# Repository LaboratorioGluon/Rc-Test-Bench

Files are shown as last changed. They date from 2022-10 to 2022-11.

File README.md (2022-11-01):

# Rc-Test-Bench

Projecto para caracterización de motores RC.

## Componentes:

- STM32 [Link](https://s.click.aliexpress.com/e/_Dma6yBh)
- Célula de Carga (El peso que miden depende del motor que quieras probar) [Link](https://s.click.aliexpress.com/e/_DmU0uxv)
- Hx711 [Link](https://s.click.aliexpress.com/e/_Dd5aIMT)
- Modulo: sensor de corriente INA219 [Link](https://s.click.aliexpress.com/e/_Dmx4wbh)
- ACS712-20A [Link](https://s.click.aliexpress.com/e/_DkJqOTh)

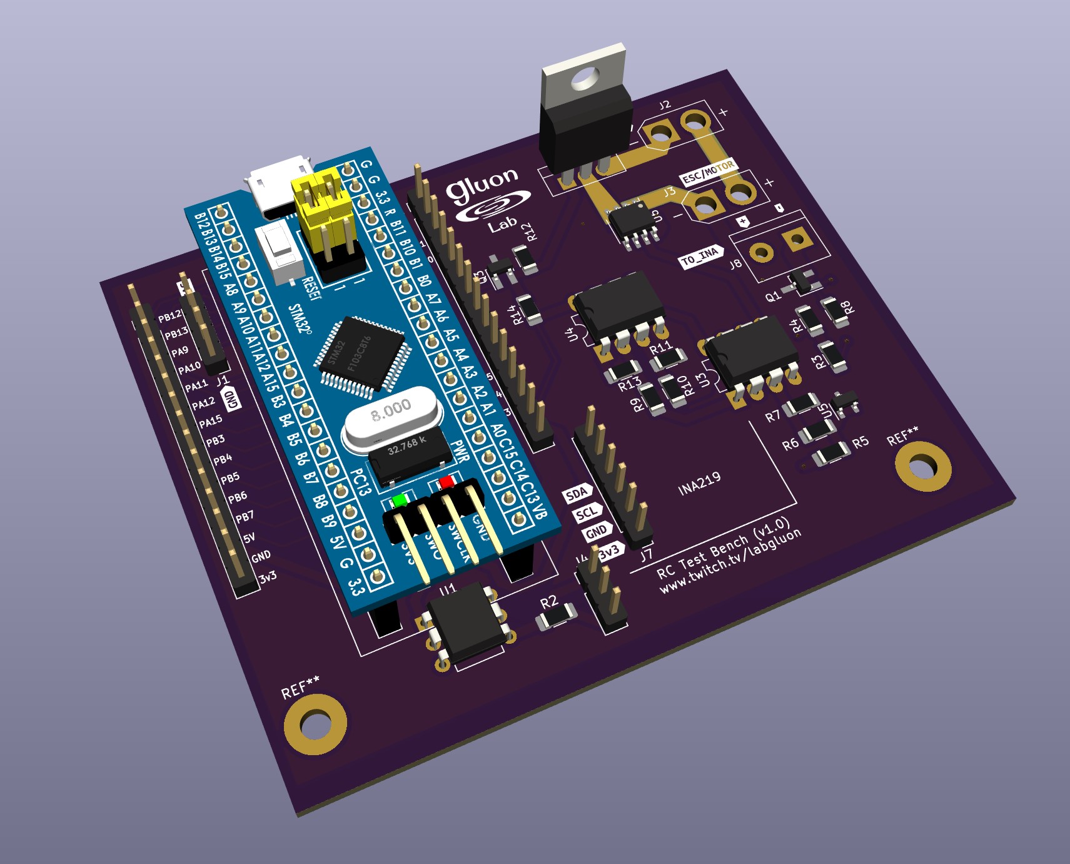
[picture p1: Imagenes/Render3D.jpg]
Render PCB


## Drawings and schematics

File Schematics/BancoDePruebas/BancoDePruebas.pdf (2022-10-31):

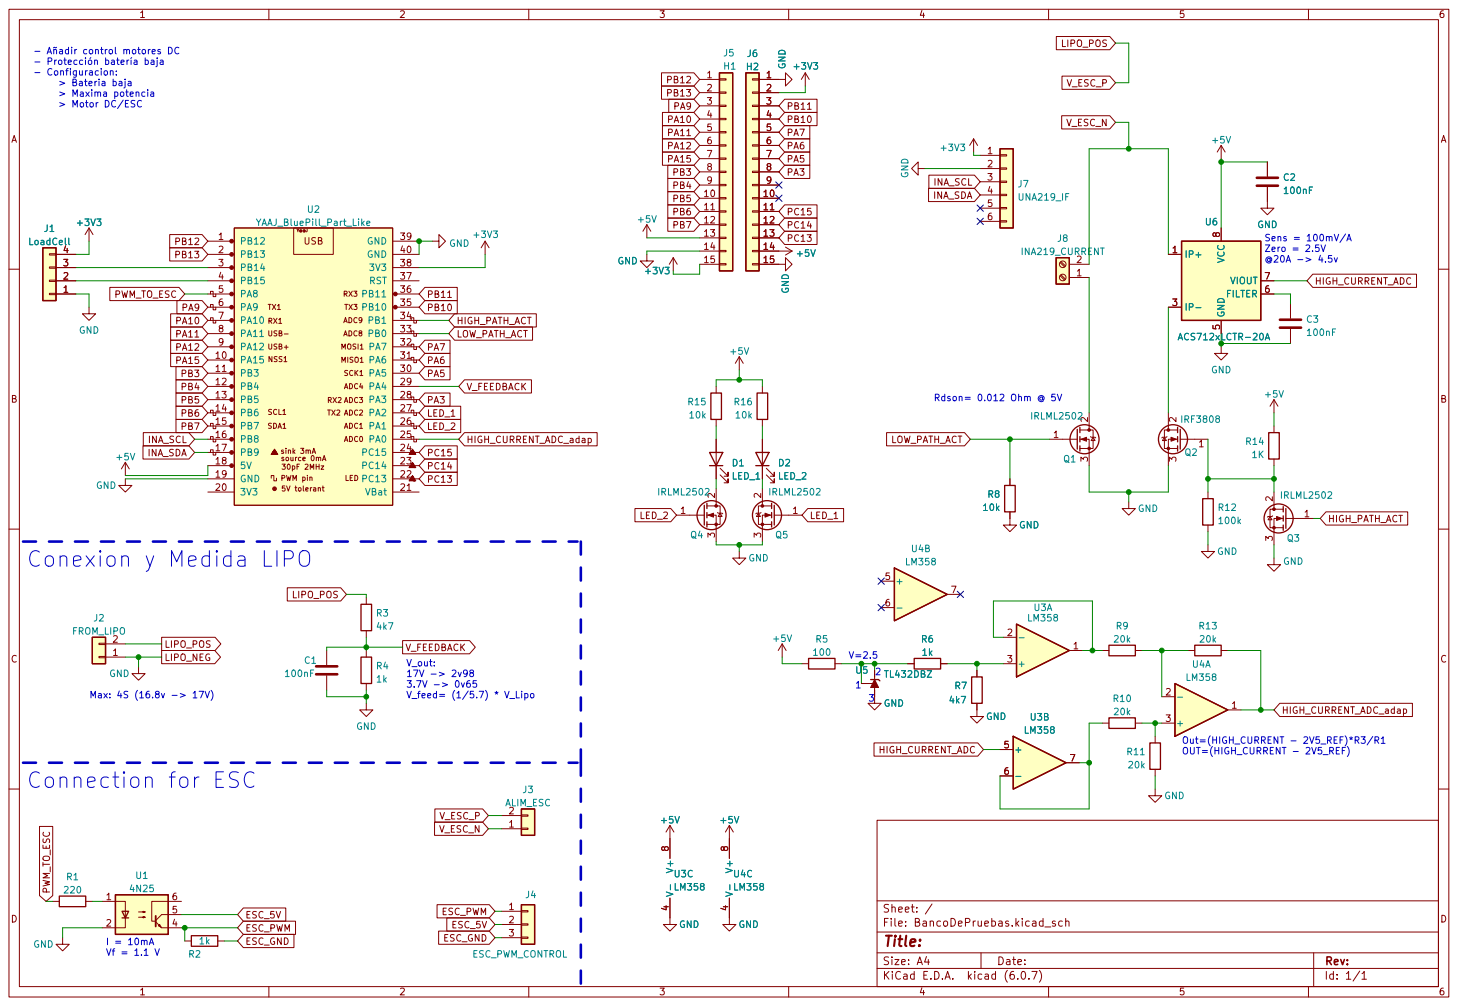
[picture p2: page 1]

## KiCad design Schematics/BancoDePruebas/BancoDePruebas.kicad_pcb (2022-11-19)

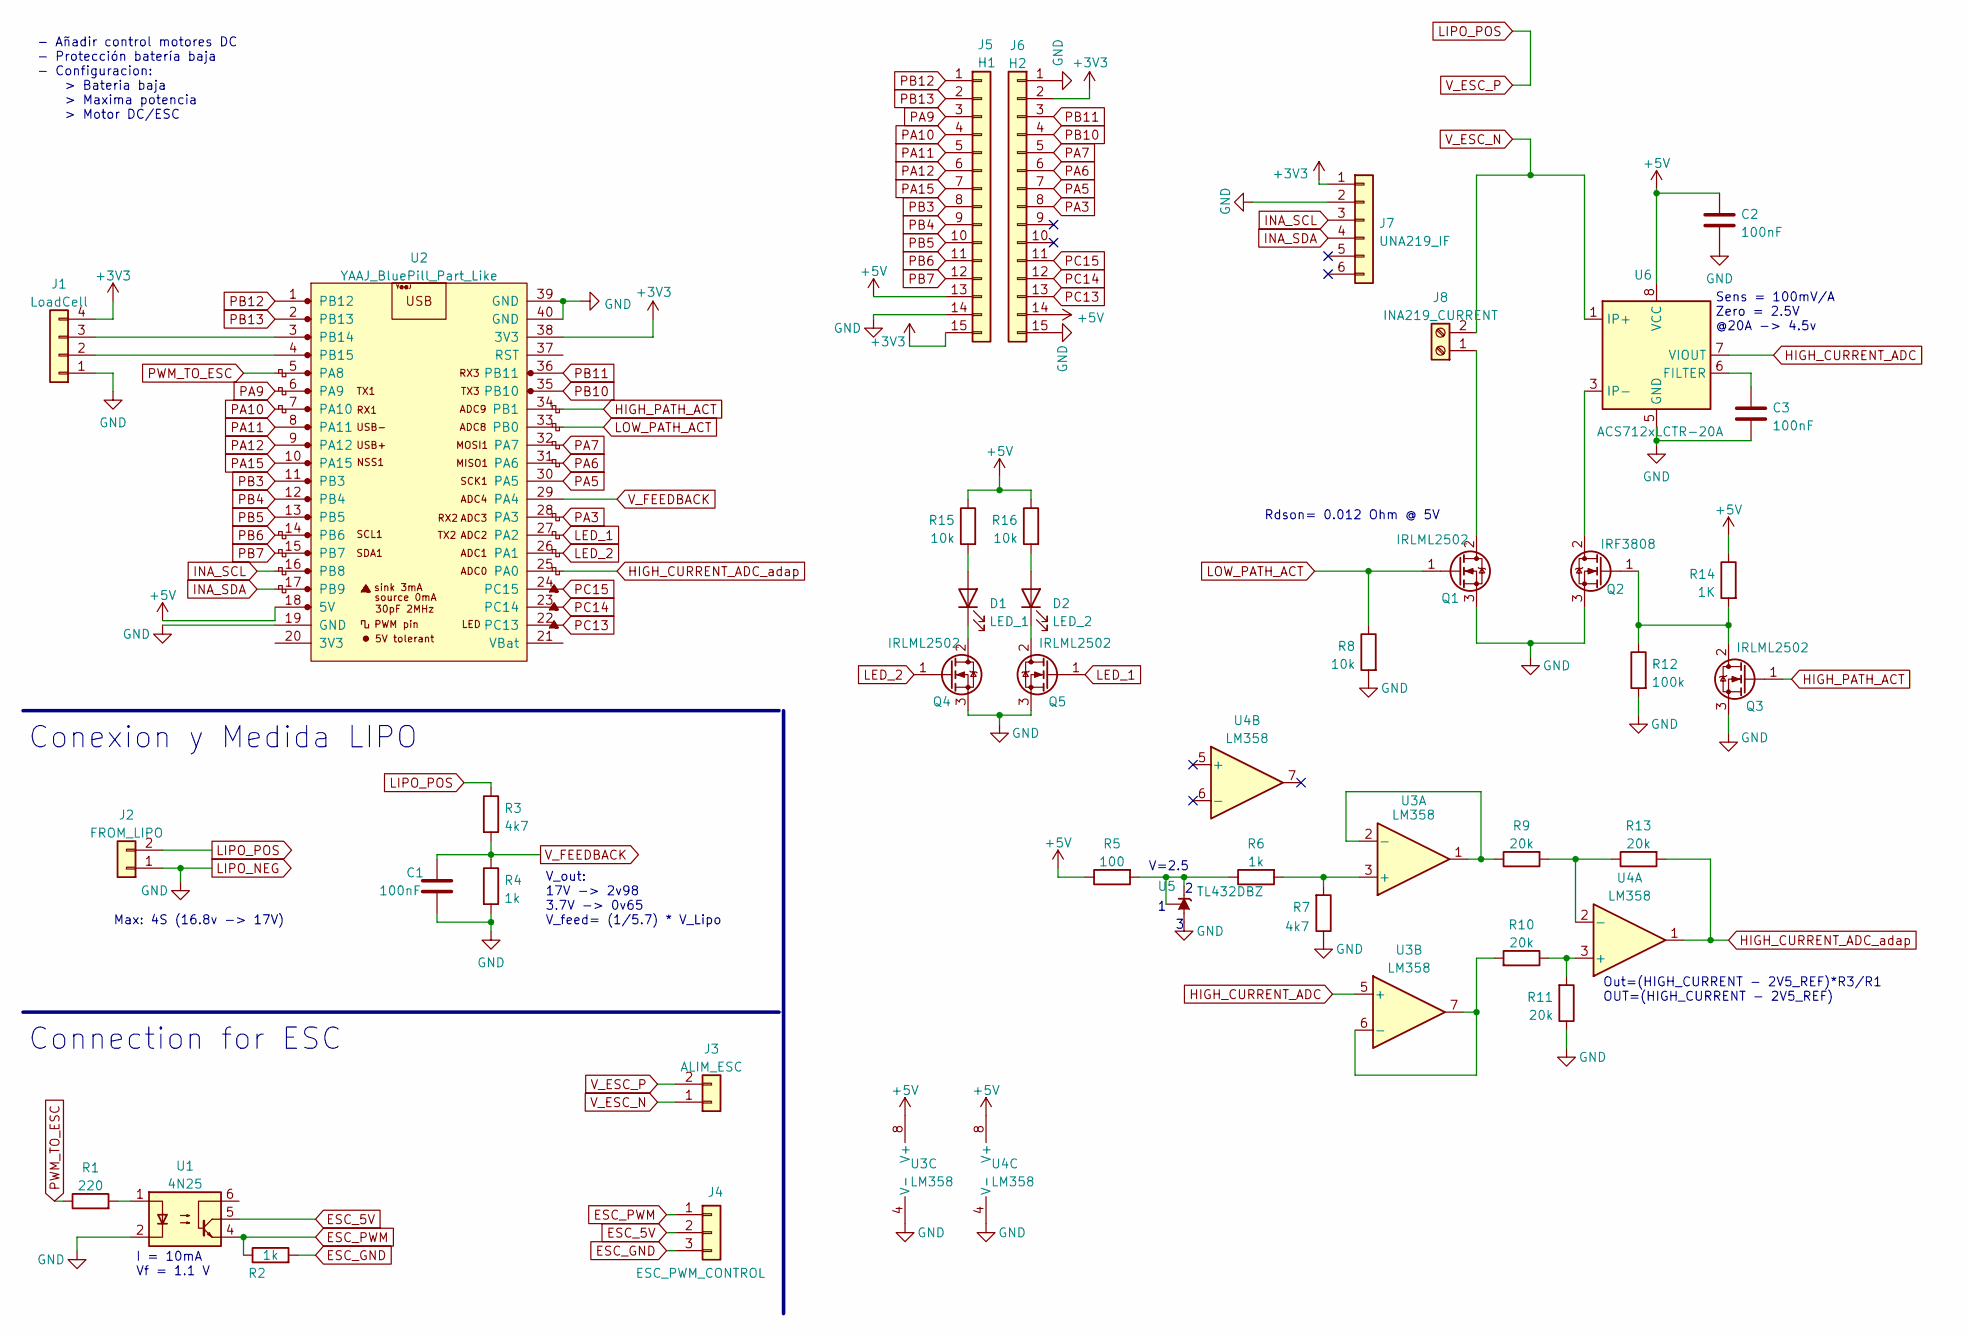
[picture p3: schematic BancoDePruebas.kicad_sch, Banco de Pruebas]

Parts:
C1, C2, C3: 100nF; C_1206_3216Metric_Pad1.33x1.80mm_HandSolder
D1: LED_1; LED_D5.0mm
D2: LED_2; LED_D5.0mm
J1: LoadCell; PinHeader_1x04_P2.54mm_Vertical
J2: FROM_LIPO; AMASS_XT30U-F_1x02_P5.0mm_Vertical
J3: ALIM_ESC; AMASS_XT30U-F_1x02_P5.0mm_Vertical
J4: ESC_PWM_CONTROL; PinHeader_1x03_P2.54mm_Vertical
J5: H1; PinHeader_1x15_P2.54mm_Vertical
J6: H2; PinHeader_1x15_P2.54mm_Vertical
J7: UNA219_IF; PinHeader_1x06_P2.54mm_Vertical
J8: INA219_CURRENT; TerminalBlock_bornier-2_P5.08mm
Q1, Q3, Q4, Q5: IRLML2502; SOT-23_Handsoldering
Q2: IRF3808; TO-220-3_Vertical
R1: 220; R_1206_3216Metric_Pad1.30x1.75mm_HandSolder
R2, R4, R6: 1k; R_1206_3216Metric_Pad1.30x1.75mm_HandSolder
R3, R7: 4k7; R_1206_3216Metric_Pad1.30x1.75mm_HandSolder
R5: 100; R_1206_3216Metric_Pad1.30x1.75mm_HandSolder
R8, R15, R16: 10k; R_1206_3216Metric_Pad1.30x1.75mm_HandSolder
R9, R10, R11, R13: 20k; R_1206_3216Metric_Pad1.30x1.75mm_HandSolder
R12: 100k; R_1206_3216Metric_Pad1.30x1.75mm_HandSolder
R14: 1K; R_1206_3216Metric_Pad1.30x1.75mm_HandSolder
U1: 4N25; DIP-6_W7.62mm
U2: YAAJ_BluePill_Part_Like; YAAJ_BluePill_1b
U3, U4: LM358; SOP-8_3.9x4.9mm_P1.27mm
U5: TL432DBZ; SOT-23
U6: ACS712xLCTR-20A; SOIC-8_3.9x4.9mm_P1.27mm

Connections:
+3V3: J1.4, J5.15, J6.2, J7.1, U2.38 (3V3)
+5V: C2.1, J5.13, J6.14, R5.1, R14.1, R15.1, R16.1, U2.18 (5V), U3.8 (V+), U4.8 (V+), U6.8 (VCC)
ESC_5V: J4.2, U1.5
ESC_GND: J4.3, R2.2
ESC_PWM: J4.1, R2.1, U1.4
HIGH_CURRENT_ADC: U3.5 (+), U6.7 (VIOUT)
HIGH_CURRENT_ADC_adap: R13.2, U2.25 (PA0), U4.1
HIGH_PATH_ACT: Q3.1 (G), U2.34 (PB1)
INA_SCL: J7.3, U2.16 (PB8)
INA_SDA: J7.4, U2.17 (PB9)
LED_1: Q5.1 (G), U2.27 (PA2)
LED_2: Q4.1 (G), U2.26 (PA1)
LIPO_NEG: C1.2, C2.2, C3.2, J1.1, J2.1, J5.14, J6.1, J6.15, J7.2, Q1.3 (S), Q2.3 (S), Q3.3 (S), Q4.3 (S), Q5.3 (S), R4.2, R7.1, R8.2, R11.1, R12.2, U1.2, U2.19 (GND), U2.39 (GND), U2.40 (GND), U3.4 (V-), U4.4 (V-), U5.3 (A), U6.5 (GND)
LIPO_POS: J2.2, J3.2, R3.1
LOW_PATH_ACT: Q1.1 (G), R8.1, U2.33 (PB0)
unnamed: D1.1 (K), Q4.2 (D)
unnamed: D1.2 (A), R15.2
unnamed: D2.1 (K), Q5.2 (D)
unnamed: D2.2 (A), R16.2
unnamed: J1.2, U2.4 (PB15)
unnamed: J1.3, U2.3 (PB14)
unnamed: J8.1, Q1.2 (D)
unnamed: Q2.1 (G), Q3.2 (D), R12.1, R14.2
unnamed: Q2.2 (D), U6.3 (IP-), U6.4 (IP-)
unnamed: R1.2, U1.1
unnamed: R5.2, R6.1, U5.1 (REF), U5.2 (K)
unnamed: R6.2, R7.2, U3.3 (+)
unnamed: R9.1, U3.1, U3.2 (-)
unnamed: R10.1, R11.2, U4.3 (+)
unnamed: R10.2, U3.6 (-), U3.7
unnamed: R9.2, R13.1, U4.2 (-)
unnamed: C3.1, U6.6 (FILTER)
PA3: J6.8, U2.28 (PA3)
PA5: J6.7, U2.30 (PA5)
PA6: J6.6, U2.31 (PA6)
PA7: J6.5, U2.32 (PA7)
PA9: J5.3, U2.6 (PA9)
PA10: J5.4, U2.7 (PA10)
PA11: J5.5, U2.8 (PA11)
PA12: J5.6, U2.9 (PA12)
PA15: J5.7, U2.10 (PA15)
PB3: J5.8, U2.11 (PB3)
PB4: J5.9, U2.12 (PB4)
PB5: J5.10, U2.13 (PB5)
PB6: J5.11, U2.14 (PB6)
PB7: J5.12, U2.15 (PB7)
PB10: J6.4, U2.35 (PB10)
PB11: J6.3, U2.36 (PB11)
PB12: J5.1, U2.1 (PB12)
PB13: J5.2, U2.2 (PB13)
PC13: J6.13, U2.22 (PC13)
PC14: J6.12, U2.23 (PC14)
PC15: J6.11, U2.24 (PC15)
PWM_TO_ESC: R1.1, U2.5 (PA8)
V_ESC_N: J3.1, J8.2, U6.1 (IP+), U6.2 (IP+)
V_FEEDBACK: C1.1, R3.2, R4.1, U2.29 (PA4)

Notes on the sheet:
- Añadir control motores DC - Protección batería baja - Configuracion: > Bateria baja > Maxima potencia > Motor DC/ESC
Out=(HIGH_CURRENT - 2V5_REF)*R3/R1 OUT=(HIGH_CURRENT - 2V5_REF)
Connection for ESC
V_out: 17V -> 2v98 3.7V -> 0v65 V_feed= (1/5.7) * V_Lipo
Max: 4S (16.8v -> 17V)
Rdson= 0.012 Ohm @ 5V
I = 10mA Vf = 1.1 V
V=2.5
Sens = 100mV/A Zero = 2.5V @20A -> 4.5v
Conexion y Medida LIPO

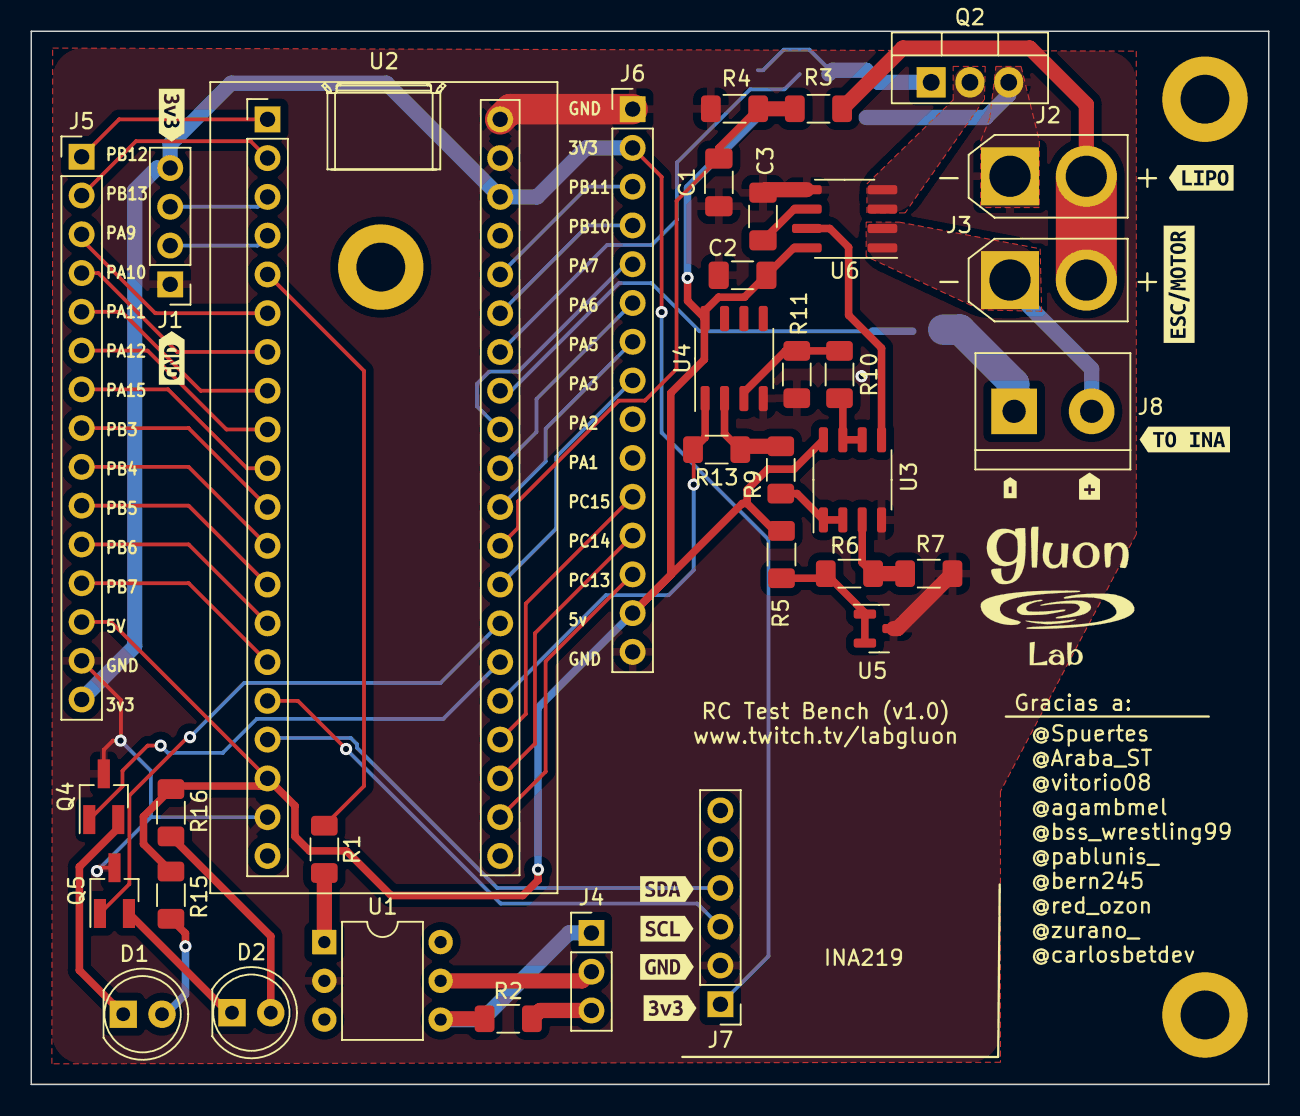
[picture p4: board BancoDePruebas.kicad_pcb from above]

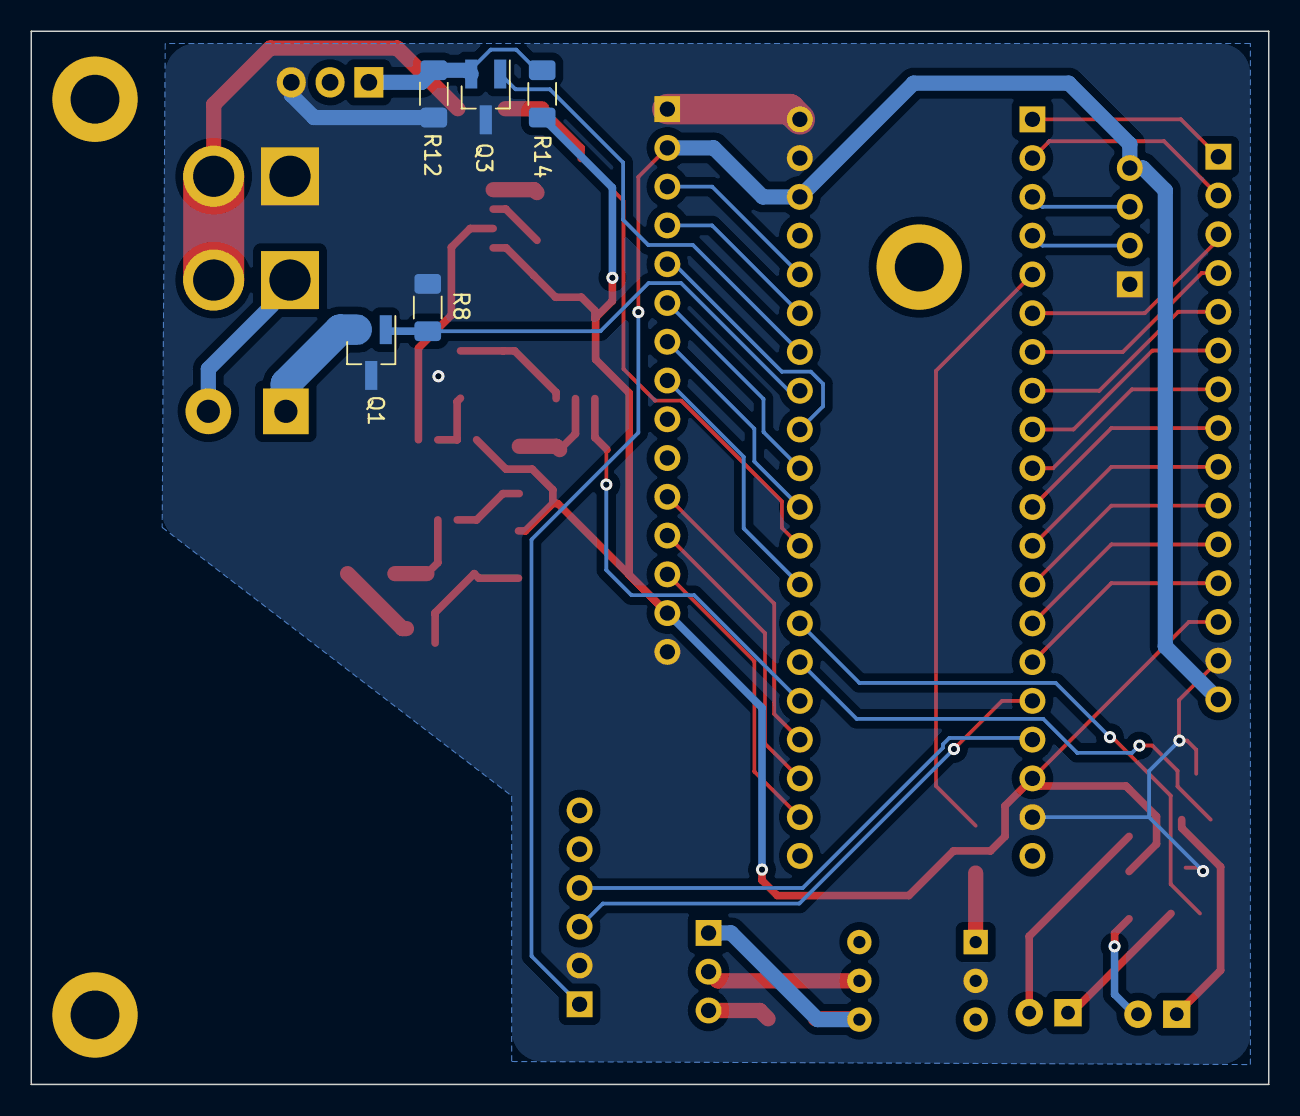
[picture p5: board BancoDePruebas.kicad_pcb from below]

Board: 2 copper layers, 81.1 x 69.0 mm, 51 parts (5 on the bottom side), 56 nets.

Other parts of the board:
kibuzzard-635D7BB9: G***; kibuzzard-635D7BB9
kibuzzard-635D7BC7: G***; kibuzzard-635D7BC7
kibuzzard-6356CD5A, kibuzzard-6356CD5A#2: G***; kibuzzard-6356CD5A
kibuzzard-6356CD7C: G***; kibuzzard-6356CD7C
kibuzzard-6356CD66, kibuzzard-6356CD66#2: G***; kibuzzard-6356CD66
kibuzzard-6356CD87: G***; kibuzzard-6356CD87
kibuzzard-6356CE02: G***; kibuzzard-6356CE02
kibuzzard-6356CE38: G***; kibuzzard-6356CE38
kibuzzard-6356CE47: G***; kibuzzard-6356CE47

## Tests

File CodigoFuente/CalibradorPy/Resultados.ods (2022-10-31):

Peso | Valor
45 | 13880 | 308,444444444444
189 | 58600 | 310,05291005291
245 | 76300 | 311,428571428571
918 | 284900 | 310,348583877996
 | Max | Min | Mean
44 | 13785 | 14037 | 13908 | 316,090909090909
185 | 58634 | 58435 | 58562 | 316,551351351351
245 | 76341 | 76211 | 76281 | 311,351020408163
918 | 285211 | 284946 | 285082 | 310,546840958606

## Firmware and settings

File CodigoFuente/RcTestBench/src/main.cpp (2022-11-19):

#include <stm32f1xx.h>

#include <hx711.h>
#include <Servo.h>

#include "basicConfig.h"
#include "Timers.h"
#include "Comms.h"
#include "CircularBuffer.h"
#include "TLVManager.h"

#include "Sensores.h"
#include "PcMessages.h"

#include <stdio.h>
#include <stdlib.h>
#include <string.h>

#include "USB\usb_device.h"
#include "STM32_USB_Device_Library\Class\usbd_cdc.h"
#include "USB\usbd_cdc_if.h"

#include "ina219.h"

#define NUMERO_ITERACIONES (60)

#define EMERGENCY_STOP_TIME (400)

CircularBuffer<uint8_t> uartBuffer(200);
CircularBuffer<uint8_t> usbBuffer(200);
TLV gTlvManager;

Servo ESC;

extern USBD_HandleTypeDef hUsbDeviceFS;
extern "C"
{

    void USART1_IRQHandler(void)
    {
        uint32_t isrflags = READ_REG(huart1.Instance->SR);

        if ((isrflags & USART_SR_RXNE) != RESET)
        {
            uartBuffer.Write(huart1.Instance->DR & 0xFF);
        }

        HAL_NVIC_ClearPendingIRQ(USART1_IRQn);
    }

    void Error_Handler() {}
}

void masterStartMeasuring()
{
    // Connect to ESC and calibrate
    CDC_Transmit_FS((uint8_t *)"  Comienzo calibracion .", 25);
    ESC.setOutMs(2);
    HAL_Delay(1000);

    // Give power to the ESC.

    // Configure current path
    Sensores::currentSensing.setCurrentPath(1);
    Sensores::currentSensing.startMeasuring();

    for (int i = 0; i < 20; i++)
    {
        ESC.setOutMs(2.0f - (i * 1.0f / 20.0f));
        CDC_Transmit_FS((uint8_t *)".", 1);
        HAL_Delay(100);
    }

    CDC_Transmit_FS((uint8_t *)" FIN\n", 5);

    HAL_Delay(500);
}

void masterStopMeasuring()
{
    ESC.setOutMs(1);
    Sensores::currentSensing.stopMeasuring();
}

enum CMD
{
    NOTHING = 0,
    SET_PWM,
    START_RUN,
    READ_CURRENT,
    PING = 0xAA
};

uint8_t USB_RecvBuffer[256];

int main()
{

    HAL_Init();

    SystemClock_Config();

    uartBuffer.Init();
    gTlvManager.Init();

    InitTimers();
    // InitUART();
    __HAL_RCC_GPIOB_CLK_ENABLE();
    __HAL_RCC_GPIOA_CLK_ENABLE();
    __HAL_RCC_TIM1_CLK_ENABLE();
    __HAL_RCC_AFIO_CLK_ENABLE();

    __HAL_RCC_AFIO_CLK_ENABLE();
    __HAL_RCC_PWR_CLK_ENABLE();

    GPIO_InitTypeDef GpioUSBHack;
    /* libopencm3
        gpio_set_mode(GPIOA, GPIO_MODE_OUTPUT_2_MHZ,
              GPIO_CNF_OUTPUT_PUSHPULL, GPIO12);
    gpio_clear(GPIOA, GPIO12);
    msleep(5); //delay
    */

    __HAL_RCC_GPIOA_CLK_ENABLE();
    GpioUSBHack.Mode = GPIO_MODE_OUTPUT_PP;
    GpioUSBHack.Pin = GPIO_PIN_12;
    GpioUSBHack.Pull = GPIO_PULLUP;
    GpioUSBHack.Speed = GPIO_SPEED_FREQ_HIGH;
    HAL_GPIO_Init(GPIOA, &GpioUSBHack);

    HAL_GPIO_WritePin(GPIOA, GPIO_PIN_12, GPIO_PIN_RESET);
    HAL_Delay(50);


    memset(USB_RecvBuffer, 0, 256);
    MX_USB_DEVICE_Init();

    // Inicializamos sensores
    Sensores::Init();

    // PWM output
    ESC.Init(TIM1, 1, GPIOA, GPIO_PIN_8);

    PcMessagesController PcMessages(&usbBuffer);


    float pwmOut = 1.4;
    float delta_pwm;
    char buf[150];
    uint32_t buf_cnt=0;
    volatile float fValue;

    uint8_t bufferlocal[200];

    uint8_t last_data;
    tlv_command last_tlv;
    uint32_t last_received_data_time = 0;
    uint32_t last_received_ping = 0;

    uint32_t swWatchdogTime=0;
    uint8_t isOk;
    


    while (1)
    {

        if (!usbBuffer.isEmpty())
        {

            if ((HAL_GetTick() - last_received_data_time) > 200)
            {
                gTlvManager.Timeout();
            }

            last_received_data_time = HAL_GetTick();
            memset(bufferlocal, 0, 200);

            while (!usbBuffer.isEmpty())
            {
                usbBuffer.Read(&last_data);
                gTlvManager.addData(last_data);
            }

            if (gTlvManager.getLastTlv(&last_tlv) == TLV_OK)
            {
                switch ((CMD)last_tlv.tag)
                {
                case CMD::NOTHING:
                    break;
                case CMD::SET_PWM:
                    pwmOut = (float)last_tlv.data[0] * 1.0f / 100.0f;
                    ESC.setOutMs(pwmOut);
                    PcMessages.sendDebug("Setting PWM: %d\n", (int)pwmOut);
                    break;

                case CMD::START_RUN:

                    PcMessages.sendDebug("\n===Iniciando Medidas===\n");

                    delta_pwm = (last_tlv.data[0] * 1.0f / 100.0f) / ((float)NUMERO_ITERACIONES);

                    PcMessages.sendDebug("  Maximo: %d\n",(int)last_tlv.data[0]);
                    pwmOut = 1.0f;
                    masterStartMeasuring();


                    Sensores::currentSensing.setConfig(300, 10);

                    isOk = true;
                    last_received_ping = HAL_GetTick();

                    for (uint8_t iteracion = 0; (iteracion < NUMERO_ITERACIONES) && isOk; iteracion++)
                    {

                        // Si llega algo por USB cancelamos.
                        if (!usbBuffer.isEmpty())
                        {
                            
                            while (!usbBuffer.isEmpty())
                            {
                                usbBuffer.Read(&last_data);
                                gTlvManager.addData(last_data);
                            }

                            
                            while(gTlvManager.getLastTlv(&last_tlv) == TLV_OK)
                            {
                                //PcMessages.sendDebug("Received TAG: %d", last_tlv.tag);
                                // Tenemos un mensaje pero no es ping
                                if(last_tlv.tag != CMD::PING)
                                {
                                    isOk = false;
                                }
                                else
                                {
                                    last_received_ping = HAL_GetTick();
                                }
                            }
                            
                        }

                        // Comprobamos tiempo desde ultimo ping
                        if((HAL_GetTick()-last_received_ping) > EMERGENCY_STOP_TIME)
                        {
                            isOk = false;
                        }

                        // Comprobacion nivel de bateria
                        if( Sensores::lipoFeedback.GetVoltageMv(3) < 7500)
                        {
                            isOk = false;
                        }

                        if (isOk)
                        {
                            pwmOut = 1.0f + iteracion * delta_pwm;
                            ESC.setOutMs(pwmOut);
                            HAL_Delay(10);
                            fValue = Sensores::hx711.getValue(5);

                            PcMessages.sendTestData(
                                pwmOut,
                                fValue,
                                Sensores::currentSensing.readCurrent(),
                                Sensores::lipoFeedback.GetVoltageMv(3)
                            );
                        }
                        swWatchdogTime = HAL_GetTick();

                        /*while(usbBuffer.isEmpty())
                        {
                            if((HAL_GetTick() - swWatchdogTime) > EMERGENCY_STOP_TIME)
                            {
                                isOk = false;
                                break;
                            }
                        }*/
                    }
                    Sensores::currentSensing.stopMeasuring();
                    ESC.setOutMs(1.0f);
                    break;

                case CMD::READ_CURRENT:
                    while (usbBuffer.isEmpty())
                    {
                        sprintf(buf, "Current: %d\n", Sensores::currentSensing.readCurrent());
                        CDC_Transmit_FS((uint8_t *)buf, strlen(buf));
                    }
                    break;
                }
            }
        }

        memset(buf, 0, 150);

    }

    return 0;
}

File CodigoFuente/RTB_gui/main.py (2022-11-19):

from PyQt5.QtGui import *
from PyQt5.QtWidgets import *
from PyQt5.QtCore import *
from PyQt5 import uic

import sys

from SerialThread import SerialReader

from tab1 import Tab1Info
from configTab import configTab

import pyqtgraph as pg
pg.setConfigOption('background','w')
pg.setConfigOption('foreground','k')
pg.setConfigOption('antialias',False)

#QApplication.setGraphicsSystem('opengl')

# @TODO: Boton de reconectar

class Ui(QMainWindow):
    def __init__(self):
        super(Ui, self).__init__() # Call the inherited classes __init__ method
        uic.loadUi('MainGUI.ui', self) # Load the .ui file
        
        self.threadpool = QThreadPool()
        self.sr = SerialReader()
        self.sr.signals.newData.connect(self.updateSerial)
        self.sr.signals.newValues.connect(self.updatePlot)


        self.setpwm = self.findChild(QPushButton, 'setPwmButton')
        self.setpwm.clicked.connect(self.setPwm)

        self.startbutton = self.findChild(QPushButton, 'StartProcess')
        self.startbutton.clicked.connect(self.startRun)

        
        self.emergencyStop.clicked.connect(lambda data:self.sr.sendCmd(1,1))

        self.serialMonitor = self.findChild(QPlainTextEdit, 'serialMonitor')

        self.pwmvalue = self.findChild(QPlainTextEdit,'PwmValueText')
        self.pwmvalue.installEventFilter(self)
        
        self.tab1 = Tab1Info()
        self.tab1.Init(self)

        self.configTab = configTab()
        self.configTab.Init(self)


        # Init plot

        self.plotNumberOfCols = 2
        self.p1 = self.graphicsView.plotItem
        self.p2 = pg.ViewBox()
        self.p1.showAxis('right')
        self.p1.scene().addItem(self.p2)
        self.p1.getAxis('right').linkToView(self.p2)
        #self.p2.setXLink(self.p1)

        self.graphicsView.plot(title="Fuerza Generada")
        self.dataX = []
        self.dataY = [[], []]


        #self.pyqtwin = pg.GraphicsWindow()

        self.curvas = []
        self.curvas.append(self.p1.plot(pen=pg.mkPen(color='k',width=3)))
        self.curvas.append(pg.PlotCurveItem(pen=pg.mkPen(color='r',width=3)))
        #self.curvas.append(pg.PlotCurveItem(pen=pg.mkPen(color='g',width=3)))
        self.p2.addItem(self.curvas[-1])
        #self.curvas.append(self.graphicsView.plot([0]*self.plotNumberOfCols, [0]*self.plotNumberOfCols, pen=pg.mkPen(color='k',width=3)))  ## setting pen=None disables line drawing
        #self.graphicsView.disableAutoRange()
        

        self.show() # Show the GUI

    def updatePlot(self, data):
        self.dataX.append(data[0])
        #for i in range(len(data)-1):
        self.voltageLabel.setText(str(data[3]/1000) + " V")
        for i in range(2):
            self.dataY[i].append(data[i+1])
            #self.curvas[i].setData(self.dataX, self.dataY[i])
            #if i == 0:
            self.curvas[i].setData(self.dataX, self.dataY[i])
            
        self.p2.setGeometry(self.p1.vb.sceneBoundingRect())
        return

        """if len(self.dataY) > 200:
            self.dataY = self.dataY[1:]
            self.dataX = self.dataX[1:]"""

        print(data)
        self.curvas[-1].setData(self.dataX, self.dataY)

    def setPwm(self, data):
        self.sr.sendCmd(1, int(float(self.pwmvalue.toPlainText())*100.0))

    def updateSerial(self, data):
        self.serialMonitor.insertPlainText(data)

    def startRun(self, data):
        #self.dataX = []
        #self.dataY = []
        #self.curvas[-1].setData(self.dataX, self.dataY)
        if self.configTab.isConfigReady == False:
            self.serialMonitor.insertPlainText("Configuration NOT ready!\n")
        self.dataX = []
        self.dataY = [[], []]
        for i in range(2):
            self.curvas[i].setData(self.dataX, self.dataY[i])
            
        self.sr.sendCmd(2,35)

    def startReadCurrent(self):
        self.sr.sendCmd(3)

    def closeEvent(self, event):
        self.sr.close()
        self.threadpool.waitForDone()
        event.accept()

    def eventFilter(self, obj, event):
        if event.type() == QEvent.KeyPress and obj is self.pwmvalue:
            if event.key() in [Qt.Key_Return, Qt.Key_Enter] and self.pwmvalue.hasFocus():
                print('Enter pressed')
                self.setPwm(None)
                self.pwmvalue.clear()
        return super().eventFilter(obj, event)

app = QApplication(sys.argv) # Create an instance of QtWidgets.QApplication
window = Ui() # Create an instance of our class
app.exec_() # Start the application

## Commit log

2022-10-31 Version pre-release
    [BancoDePruebas.kicad_pcb, BancoDePruebas.kicad_sch, BancoDePruebas_NMOS.kicad_sch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]
2022-10-31 Fixes for DRC
    [BancoDePruebas.kicad_pcb]
2022-11-06 Working ping back
    [BancoDePruebas.kicad_pcb]
2022-11-19 Added battery limit and config page
2022-11-19 Changes in UI
    [BancoDePruebas.kicad_pcb, BancoDePruebas.kicad_sch]
